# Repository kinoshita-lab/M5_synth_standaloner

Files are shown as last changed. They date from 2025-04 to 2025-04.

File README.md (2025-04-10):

# M5 Synth standaloner san

M5 Synth standaloner san is a handy PCB which enables standalone use of:
- Unit Synth https://docs.m5stack.com/ja/unit/Unit-Synth 
- Unit MIDI https://docs.m5stack.com/en/unit/Unit-MIDI

without using a microcontroller such as M5Stack/Stick. 
Both Type A and Type B MIDI IN are supported.

All other product names other than this product are trademarks or registered trademarks of their respective companies.

top
bottom
synth
midi

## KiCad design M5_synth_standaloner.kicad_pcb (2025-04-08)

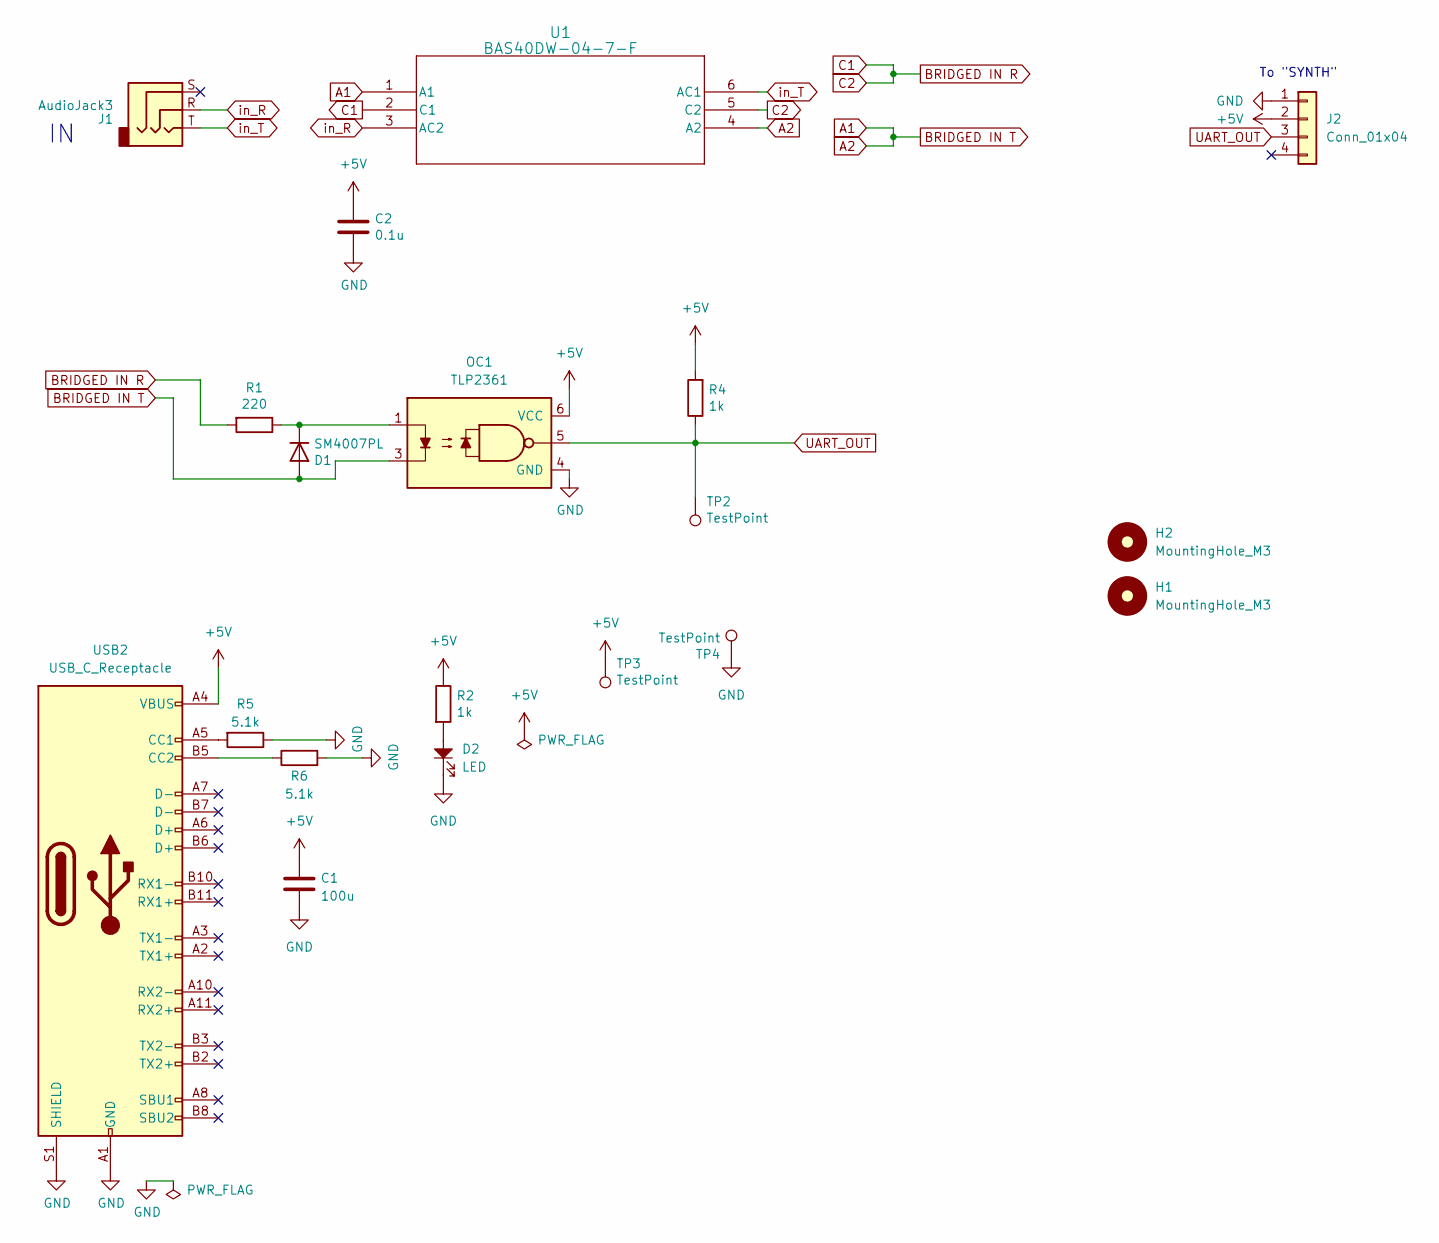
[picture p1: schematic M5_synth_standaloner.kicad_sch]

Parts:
C1: 100u; C_1206_3216Metric_Pad1.33x1.80mm_HandSolder; LCSC C15008
C2: 0.1u; C_0402_1005Metric; LCSC C1525
D1: SM4007PL; D_SOD-123; LCSC C64898
D2: LED; LED_0603_1608Metric; LCSC C965808
H1, H2: MountingHole_M3; MountingHole_3.2mm_M3
J1: AudioJack3; 3.5mm_Stereo_TRS_PJ-3210-4A_and_ST-005-G; LCSC C136686
J2: Conn_01x04; SEEEDSTUDIO_114020164; LCSC C604849
OC1: TLP2361; SO-5_4.4x3.6mm_P1.27mm; LCSC C123773
R1: 220; R_1206_3216Metric_Pad1.30x1.75mm_HandSolder; LCSC C17957
R2, R4: 1k; R_0402_1005Metric; LCSC C11702
R5, R6: 5.1k; R_0402_1005Metric; LCSC C25905
TP2, TP3, TP4: TestPoint; TestPoint_THTPad_1.0x1.0mm_Drill0.5mm
U1: BAS40DW-04-7-F; SOT-363_DIO; LCSC C134364
USB2: USB_C_Receptacle; USB_C_Receptacle_HCTL_HC-TYPE-C-16P-01A; LCSC C2894897

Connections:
+5V: C1.1, C2.1, J2.2, OC1.6 (VCC), R2.1, R4.2, TP3.1, USB2.A4 (VBUS), USB2.A9 (VBUS), USB2.B4 (VBUS), USB2.B9 (VBUS)
A1: D1.2 (A), OC1.3, U1.1 (A1), U1.4 (A2)
BRIDGED IN R: R1.2, U1.2 (C1), U1.5 (C2)
GND: C1.2, C2.2, D2.1, J2.1, OC1.4 (GND), R5.1, R6.2, TP4.1, USB2.A1 (GND), USB2.A12 (GND), USB2.B1 (GND), USB2.B12 (GND), USB2.S1 (SHIELD)
unnamed: D1.1 (K), OC1.1, R1.1
unnamed: D2.2, R2.2
unnamed: R5.2, USB2.A5 (CC1)
unnamed: R6.1, USB2.B5 (CC2)
UART_OUT: J2.3, OC1.5, R4.1, TP2.1
in_R: J1.R, U1.3 (AC2)
in_T: J1.T, U1.6 (AC1)

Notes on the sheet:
To "SYNTH"

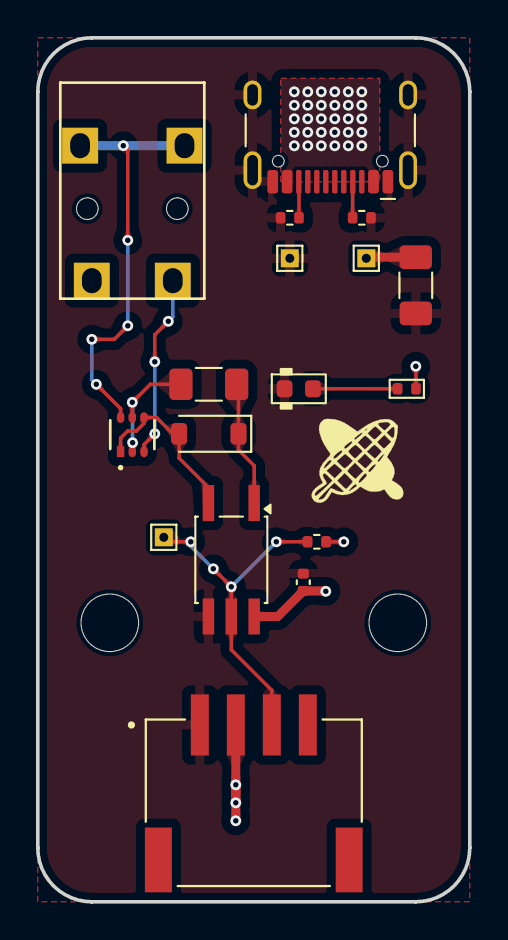
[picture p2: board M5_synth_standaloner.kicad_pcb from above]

Board: 2 copper layers, 24.0 x 48.0 mm, 19 parts (0 on the bottom side), 11 nets.
